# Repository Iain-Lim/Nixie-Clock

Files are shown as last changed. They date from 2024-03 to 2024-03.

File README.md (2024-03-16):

## Nixie_ver1
- The first board which house all the nixie tubes and the driver for it.

## Nixie2nd_ver1
- The second board which house the Arduino Nano, High Voltage Power Supply, Real-time clock, and other components
- Do note that there is a missing connection for the arduino to the ground.

## divergence_meter_ver_1_4
- Functional code for the clock/divergence meter.
- Yet to implement rolling numbers for the divegence number.

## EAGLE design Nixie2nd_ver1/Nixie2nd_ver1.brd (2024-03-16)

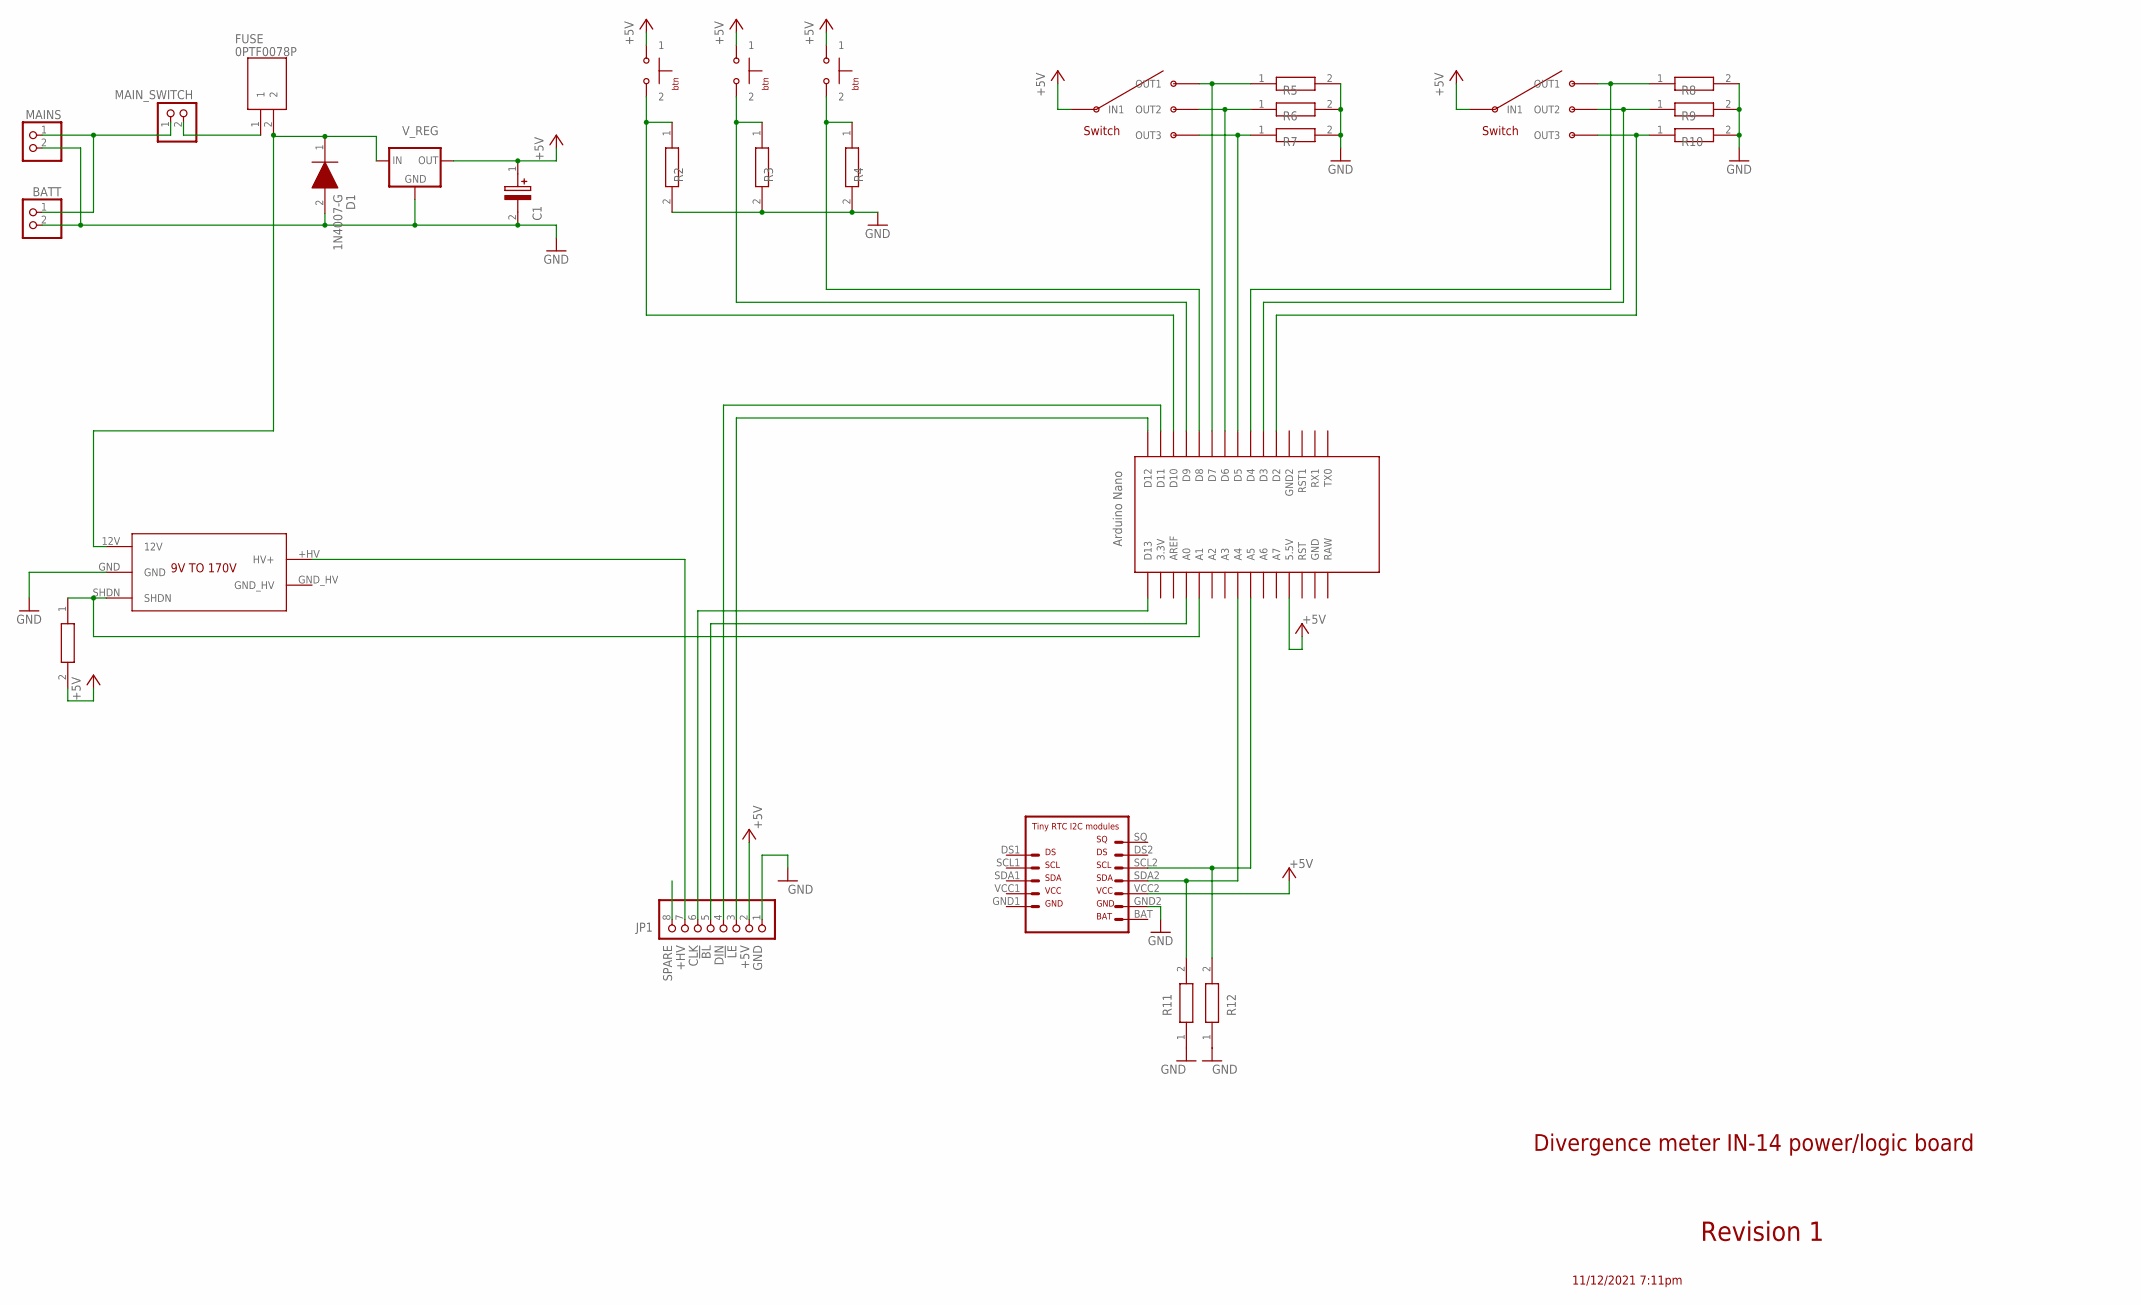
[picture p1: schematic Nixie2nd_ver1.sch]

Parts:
BATT: PINHD-1X2; 1X02
BTN_1, BTN_2, BTN_3: PUSH_BTN
C1: ESMG250ELL330ME11D; CAPPRD275W60D825H1300
D1: 1N4007-G; DIOAD1410W90L470D235
FUSE: 0PTF0078P
JP1: PINHD-1X8; 1X08
MAINS: PINHD-1X2; 1X02
MAIN_SWITCH: PINHD-1X2; 1X02
R1, R2, R3, R4, R5, R6, R7, R8, R9, R10, R11, R12: CR0805-FX-3303ELF; RESC2012X60N
SWITCH_1, SWITCH_2: 3WAY_SWITCH
U$1: NANO
U$2: VOLTAGE_9TO170VOLT_9TO170; VOLTAGE_9TO170
U$3: RTC
V_REG: 78XXS

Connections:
!BL: JP1.5, U$1.A0
!LE: JP1.3, U$1.D12
+5V: BTN_1.1, BTN_2.1, BTN_3.1, C1.1 (+), JP1.2, R1.2, SWITCH_1.IN1, SWITCH_2.IN1, U$1.5V (5.5V), U$3.VCC2, V_REG.OUT
+HV: JP1.7, U$2.+HV (HV+)
CLK: JP1.6, U$1.D13
DIN: JP1.4, U$1.D11
GND: BATT.2, C1.2 (-), D1.2 (A), JP1.1, MAINS.2, R2.2, R3.2, R4.2, R5.2, R6.2, R7.2, R8.2, R9.2, R10.2, R11.1, R12.1, U$2.GND, U$3.GND2, V_REG.GND
MAINS: BATT.1, MAINS.1, MAIN_SWITCH.1
MAINS_REG: D1.1 (K), FUSE.2, U$2.12V, V_REG.IN
unnamed: R5.1, SWITCH_1.OUT1, U$1.D7
unnamed: R6.1, SWITCH_1.OUT2, U$1.D6
unnamed: R7.1, SWITCH_1.OU3 (OUT3), U$1.D5
unnamed: R8.1, SWITCH_2.OUT1, U$1.D4
unnamed: R9.1, SWITCH_2.OUT2, U$1.D3
unnamed: R10.1, SWITCH_2.OU3 (OUT3), U$1.D2
unnamed: BTN_3.2, R4.1, U$1.D8
unnamed: BTN_2.2, R3.1, U$1.D9
unnamed: BTN_1.2, R2.1, U$1.D10
unnamed: FUSE.1, MAIN_SWITCH.2
SCL: R12.2, U$1.A5, U$3.SCL2
SDA: R11.2, U$1.A4, U$3.SDA2
SHDN: R1.1, U$1.A1, U$2.SHDN
SPARE: JP1.8

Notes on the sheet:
Divergence meter IN-14 power/logic board
11/12/2021 7:11pm
Revision 1

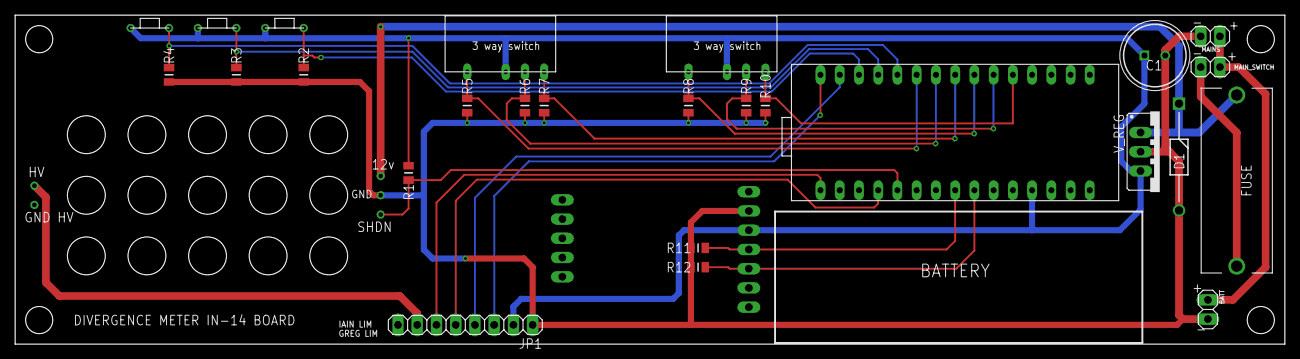
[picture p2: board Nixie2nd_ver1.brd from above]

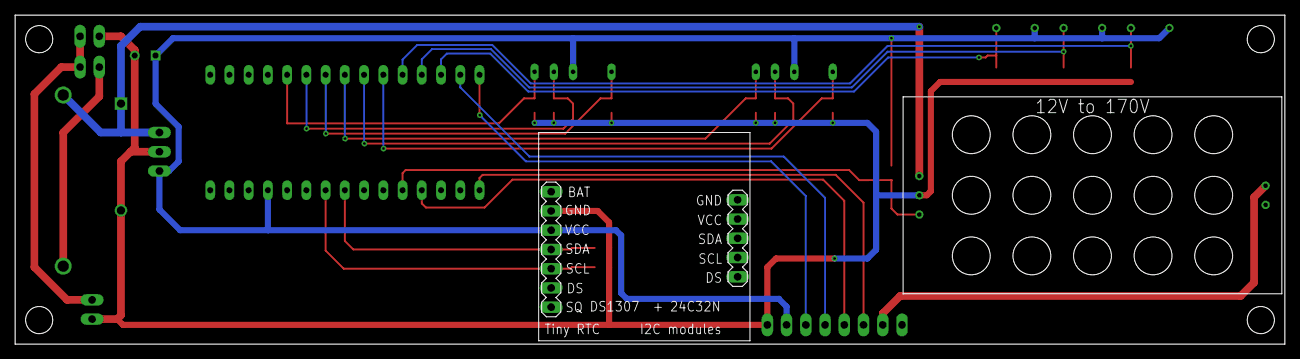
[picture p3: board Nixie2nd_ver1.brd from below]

Board: 2 copper layers, 167.6 x 43.4 mm, 28 parts (2 on the bottom side), 22 nets.

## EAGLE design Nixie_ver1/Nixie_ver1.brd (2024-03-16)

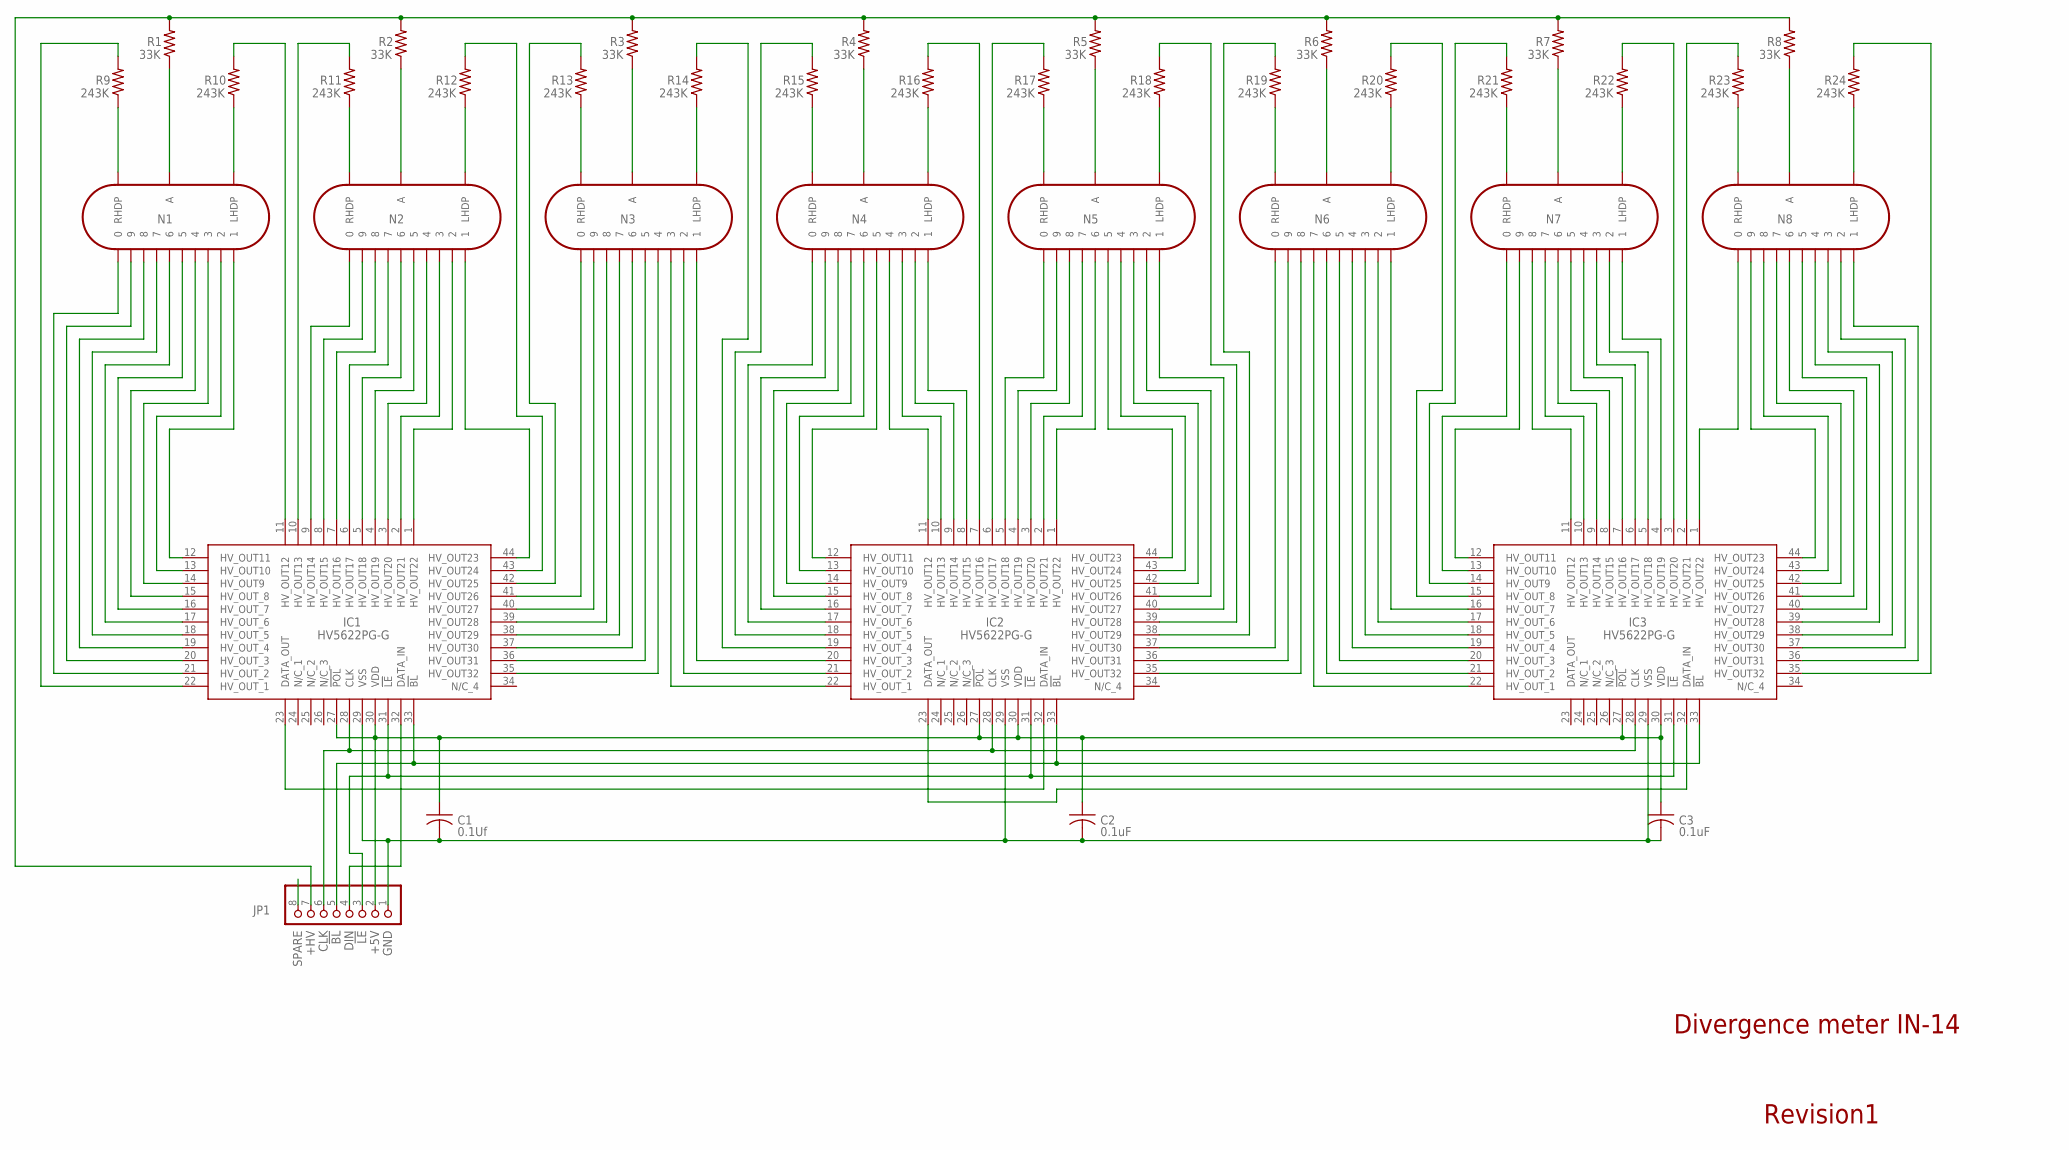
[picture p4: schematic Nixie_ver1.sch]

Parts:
C1: 0.1Uf; C025-024X044
C2, C3: 0.1uF; C025-024X044
IC1, IC2, IC3: HV5622PG-G; QFP80P1390X1390X235-44N
JP1: PINHD-1X8; 1X08
N1, N2, N3, N4, N5, N6, N7, N8: IN-14
R1, R2, R3, R4, R5, R6, R7, R8: 33K; 0204/7
R9, R10, R11, R12, R13, R14, R15, R16, R17, R18, R19, R20, R21, R22, R23, R24: 243K; 0204/7

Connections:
!BL!: IC1.33 (!BL), IC2.33 (!BL), IC3.33 (!BL), JP1.5
!LE!: IC1.31 (!LE), IC2.31 (!LE), IC3.31 (!LE), JP1.3
+5V: C1.1, C2.1, C3.1, IC1.27 (!POL), IC1.30 (VDD), IC2.27 (!POL), IC2.30 (VDD), IC3.27 (!POL), IC3.30 (VDD), JP1.2
+HV: JP1.7, R1.2, R2.2, R3.2, R4.2, R5.2, R6.2, R7.2, R8.2
CLK: IC1.28 (CLK), IC2.28 (CLK), IC3.28 (CLK), JP1.6
DIN: IC1.32 (DATA_IN), JP1.4
GND: C1.2, C2.2, C3.2, IC1.29 (VSS), IC2.29 (VSS), IC3.29 (VSS), JP1.1
unnamed: IC1.23 (DATA_OUT), IC2.32 (DATA_IN)
unnamed: IC2.23 (DATA_OUT), IC3.32 (DATA_IN)
unnamed: IC1.11 (HV_OUT12), R10.2
unnamed: IC1.13 (HV_OUT10), N1.2
unnamed: IC1.14 (HV_OUT9), N1.3
unnamed: IC1.15 (HV_OUT_8), N1.4
unnamed: IC1.16 (HV_OUT_7), N1.5
unnamed: IC1.17 (HV_OUT_6), N1.6
unnamed: IC1.18 (HV_OUT_5), N1.7
unnamed: IC1.19 (HV_OUT_4), N1.8
unnamed: IC1.20 (HV_OUT_3), N1.9
unnamed: IC1.12 (HV_OUT11), N1.1
unnamed: IC1.21 (HV_OUT_2), N1.0
unnamed: IC1.22 (HV_OUT_1), R9.2
unnamed: N1.RHDP, R9.1
unnamed: N1.LHDP, R10.1
unnamed: IC1.10 (HV_OUT13), R11.2
unnamed: N1.A, R1.1
unnamed: N2.RHDP, R11.1
unnamed: N2.A, R2.1
unnamed: N2.LHDP, R12.1
unnamed: IC1.9 (HV_OUT14), N2.0
unnamed: IC1.8 (HV_OUT15), N2.9
unnamed: IC1.7 (HV_OUT16), N2.8
unnamed: IC1.6 (HV_OUT17), N2.7
unnamed: IC1.5 (HV_OUT18), N2.6
unnamed: IC1.4 (HV_OUT19), N2.5
unnamed: IC1.3 (HV_OUT20), N2.4
unnamed: IC1.2 (HV_OUT21), N2.3
unnamed: IC1.1 (HV_OUT22), N2.2
unnamed: IC1.44 (HV_OUT23), N2.1
unnamed: IC1.43 (HV_OUT24), R12.2
unnamed: IC1.42 (HV_OUT25), R13.2
unnamed: N3.RHDP, R13.1
unnamed: N3.A, R3.1
unnamed: N3.LHDP, R14.1
unnamed: IC1.41 (HV_OUT26), N3.0
unnamed: IC1.40 (HV_OUT27), N3.9
unnamed: IC1.39 (HV_OUT28), N3.8
unnamed: IC1.38 (HV_OUT29), N3.7
unnamed: IC1.37 (HV_OUT30), N3.6
unnamed: IC1.36 (HV_OUT31), N3.5
unnamed: IC1.35 (HV_OUT32), N3.4
unnamed: IC2.22 (HV_OUT_1), N3.3
unnamed: IC2.21 (HV_OUT_2), N3.2
unnamed: IC2.20 (HV_OUT_3), N3.1
unnamed: IC2.19 (HV_OUT_4), R14.2
unnamed: IC2.18 (HV_OUT_5), R15.2
unnamed: N4.RHDP, R15.1
unnamed: N4.A, R4.1
unnamed: N4.LHDP, R16.1
unnamed: IC2.17 (HV_OUT_6), N4.0
unnamed: IC2.16 (HV_OUT_7), N4.9
unnamed: IC2.15 (HV_OUT_8), N4.8
unnamed: IC2.14 (HV_OUT9), N4.7
unnamed: IC2.13 (HV_OUT10), N4.6
unnamed: IC2.1 (HV_OUT22), N5.6
unnamed: IC2.11 (HV_OUT12), N4.4
unnamed: IC2.10 (HV_OUT13), N4.3
unnamed: IC2.9 (HV_OUT14), N4.2
unnamed: IC2.8 (HV_OUT15), N4.1
unnamed: IC2.7 (HV_OUT16), R16.2
unnamed: IC2.6 (HV_OUT17), R17.2
unnamed: N5.RHDP, R17.1
unnamed: N5.A, R5.1
unnamed: N5.LHDP, R18.1
unnamed: IC2.5 (HV_OUT18), N5.0
unnamed: IC2.4 (HV_OUT19), N5.9
unnamed: IC2.3 (HV_OUT20), N5.8
unnamed: IC2.2 (HV_OUT21), N5.7
unnamed: N6.RHDP, R19.1
unnamed: IC2.44 (HV_OUT23), N5.5
unnamed: IC2.43 (HV_OUT24), N5.4
unnamed: IC2.42 (HV_OUT25), N5.3
unnamed: IC2.41 (HV_OUT26), N5.2
unnamed: IC2.40 (HV_OUT27), N5.1
unnamed: IC2.39 (HV_OUT28), R18.2
unnamed: IC2.38 (HV_OUT29), R19.2
unnamed: IC2.12 (HV_OUT11), N4.5
unnamed: N6.A, R6.1
unnamed: N6.LHDP, R20.1
unnamed: N7.RHDP, R21.1
unnamed: N7.A, R7.1
unnamed: N7.LHDP, R22.1
unnamed: N8.RHDP, R23.1
unnamed: N8.A, R8.1
unnamed: N8.LHDP, R24.1
unnamed: IC2.37 (HV_OUT30), N6.0
unnamed: IC2.36 (HV_OUT31), N6.9
unnamed: IC2.35 (HV_OUT32), N6.8
unnamed: IC3.22 (HV_OUT_1), N6.7
unnamed: IC3.21 (HV_OUT_2), N6.6
unnamed: IC3.20 (HV_OUT_3), N6.5
unnamed: IC3.19 (HV_OUT_4), N6.4
unnamed: IC3.18 (HV_OUT_5), N6.3
unnamed: IC3.17 (HV_OUT_6), N6.2
unnamed: IC3.16 (HV_OUT_7), N6.1
unnamed: IC3.15 (HV_OUT_8), R20.2
unnamed: IC3.14 (HV_OUT9), R21.2
unnamed: IC3.13 (HV_OUT10), N7.0
unnamed: IC3.12 (HV_OUT11), N7.9
unnamed: IC3.11 (HV_OUT12), N7.8
unnamed: IC3.10 (HV_OUT13), N7.7
unnamed: IC3.9 (HV_OUT14), N7.6
unnamed: IC3.8 (HV_OUT15), N7.5
unnamed: IC3.7 (HV_OUT16), N7.4
unnamed: IC3.6 (HV_OUT17), N7.3
unnamed: IC3.5 (HV_OUT18), N7.2
unnamed: IC3.4 (HV_OUT19), N7.1
unnamed: IC3.3 (HV_OUT20), R22.2
unnamed: IC3.2 (HV_OUT21), R23.2
unnamed: IC3.1 (HV_OUT22), N8.0
unnamed: IC3.44 (HV_OUT23), N8.9
unnamed: IC3.43 (HV_OUT24), N8.8
unnamed: IC3.42 (HV_OUT25), N8.7
unnamed: IC3.41 (HV_OUT26), N8.6
unnamed: IC3.40 (HV_OUT27), N8.5
unnamed: IC3.39 (HV_OUT28), N8.4
unnamed: IC3.38 (HV_OUT29), N8.3
unnamed: IC3.37 (HV_OUT30), N8.2
unnamed: IC3.36 (HV_OUT31), N8.1
unnamed: IC3.35 (HV_OUT32), R24.2
SPARE: JP1.8

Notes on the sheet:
Divergence meter IN-14
Revision1

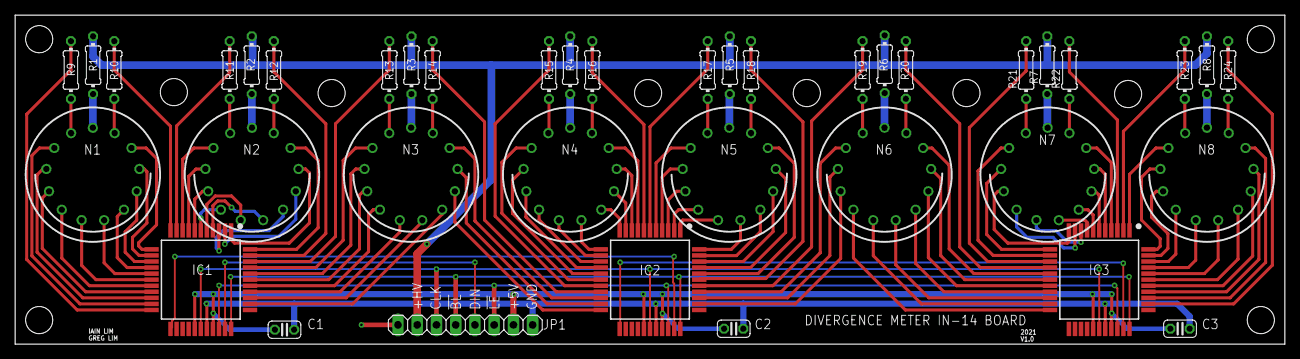
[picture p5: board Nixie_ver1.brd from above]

Board: 2 copper layers, 167.6 x 43.4 mm, 39 parts (0 on the bottom side), 129 nets.

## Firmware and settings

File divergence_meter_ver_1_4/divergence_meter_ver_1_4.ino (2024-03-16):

#include <Wire.h>
#include <TimeLib.h>
#include <DS1307RTC.h>

int latchPin = 12;
int clockPin = 13;
int dataPin = 11;
int blankPin = 14;

int SHDNPin = 15;

//Mode
int SW1_R = 2; //Divergence
int SW1_M = 3; //Date
int SW1_L = 4; //Time

//Settings
int SW2_R = 5; //Special
int SW2_M = 6; //Setting
int SW2_L = 7; //Normal

//buttons
int BTN_L = 8; //Next
int BTN_M = 9; //Up
int BTN_R = 10;//Down

/*
  SCLPin = 19
  SDAPin = 18
*/


bool tubeDigitData[8][12] = {0};
//first value is the tube, 0 is MSB;
//second value is the value, 0 is 0, 10 is Ldot, 11 is Rdot
//bool 1 is light up

bool FinalStringData[96] = {0};
//Final data to be shifted out

bool PrevFinalStringData[96] = {0};
//Previous final data to be shifted out

int SettingBlinkTimeConst = 500; //time const for ON or OFF state when blinking in milliseconds
unsigned long SettingBlinkTime = 0; //time pass for ON or OFF state when blinking
//bool SettingBlink = 0; //ON or OFF state when blinking
int SettingPair = 1; //The pair of digits being set with 1(hr/date), 2(min/month), 3(sec/year)
//Setting mode for Time and Date
int prev_sec = 60;
//to determine if the time has changed

int PrevStateSW1 = 1; //1:date 2:time 3:divergence
int PrevStateSW2 = 1; //1:Normal 3:setting 3:special
bool PrevStateBTN_L = 0; //Next
bool PrevStateBTN_M = 0; //Up
bool PrevStateBTN_R = 0; //Down
//previous state of the inputs

bool LowHighBTN_L = 0; //Next
bool LowHighBTN_M = 0; //Up
bool LowHighBTN_R = 0; //Down
//current state of the inputs

unsigned long debounceTimeBTN_L = 0;
unsigned long debounceTimeBTN_M = 0;
unsigned long debounceTimeBTN_R = 0;
int debounceTime = 50;
//debouncing
int numbertest=0;

//Divergence number
long DivergenceNum[12] = {10130426, 571024, 571015, 523299, 456903, 409420, 337187, 409431, 456914, 523307, 571046, 10130205};
long SteinsGateNum = 10048596;
int CurrentDiv = 0;

void setup() {
  //Serial.println(mainData, BIN);
  pinMode(latchPin, OUTPUT);
  pinMode(dataPin, OUTPUT);
  pinMode(clockPin, OUTPUT);
  pinMode(blankPin, OUTPUT);

  pinMode(SHDNPin, OUTPUT);

  pinMode(SW1_R, INPUT);
  pinMode(SW1_M, INPUT);
  pinMode(SW1_L, INPUT);
  pinMode(SW2_R, INPUT);
  pinMode(SW2_M, INPUT);
  pinMode(SW2_L, INPUT);
  pinMode(BTN_L, INPUT);
  pinMode(BTN_M, INPUT);
  pinMode(BTN_R, INPUT);

  digitalWrite(blankPin, LOW);
  digitalWrite(SHDNPin, HIGH);

  Serial.begin(9600);
  while (! Serial); // Wait untilSerial is ready
  Serial.println("Test");

  tdd_reset();
  tdd_updateShiftRegister();
  digitalWrite(blankPin, HIGH);
  digitalWrite(SHDNPin, LOW);


}

void loop() {
  bool CurrentstateBTN_L = digitalRead(BTN_L);
  bool CurrentstateBTN_M = digitalRead(BTN_M);
  bool CurrentstateBTN_R = digitalRead(BTN_R);

  if ((PrevStateBTN_L != CurrentstateBTN_L) && (millis() - debounceTimeBTN_L > debounceTime)) {
    LowHighBTN_L = 1;
    numbertest++;
  }
  else {
    LowHighBTN_L = 0;
  }
  if(CurrentstateBTN_L){
    debounceTimeBTN_L = millis();
  }

  if ((PrevStateBTN_M != CurrentstateBTN_M) && (millis() - debounceTimeBTN_M > debounceTime)) {
    LowHighBTN_M = 1;
    numbertest++;
  }
  else {
    LowHighBTN_M = 0;
  }
  if(CurrentstateBTN_M){
    debounceTimeBTN_M = millis();
  }

  if ((PrevStateBTN_R != CurrentstateBTN_R) && (millis() - debounceTimeBTN_R > debounceTime)) {
    LowHighBTN_R = 1;
    numbertest++;
  }
  else {
    LowHighBTN_R = 0;
  }
  if(CurrentstateBTN_R){
    debounceTimeBTN_R = millis();
  }

  PrevStateBTN_L = CurrentstateBTN_L;
  PrevStateBTN_M = CurrentstateBTN_M;
  PrevStateBTN_R = CurrentstateBTN_R;


  if (digitalRead(SW1_L)) {
    printDATE();
    Serial.print("Date ");
  }
  else if (digitalRead(SW1_M)) {
    printTIME();
    Serial.print("Time ");
  }
  else if (digitalRead(SW1_R)) {
    printDIVERGENCE();
    Serial.print("DIVERGENCE ");
  }
  else {
    tdd_reset();
    tubeDigitData[7][1] = 1;
  }

  tdd_updateShiftRegister();
  tdd_reset();
  Serial.println();
  Serial.print(numbertest); //test
  Serial.print("  ");       //test
  Serial.print("BTN_L:");
  Serial.print(LowHighBTN_L);
  Serial.print(" BTN_M:");
  Serial.print(LowHighBTN_M);
  Serial.print(" BTN_R:");
  Serial.print(LowHighBTN_R);
  Serial.println();
  Serial.println();

  /*print0To9DotDotRolling();
    tdd_reset();
    tdd_updateShiftRegister();
    delay(1000);*/

}


//----------------------------------
//------------FUNCTIONS-------------
//----------------------------------


//prints the current 24hr time in HH MM SS
void printTIME()
{
  tmElements_t tm;
  if (RTC.read(tm)) {
    tubeDigitData[0][tm.Hour / 10] = 1;
    tubeDigitData[1][tm.Hour % 10] = 1;

    tubeDigitData[3][tm.Minute / 10] = 1;
    tubeDigitData[4][tm.Minute % 10] = 1;

    tubeDigitData[6][tm.Second / 10] = 1;
    tubeDigitData[7][tm.Second % 10] = 1;

    if (tm.Second % 2) {
      tubeDigitData[2][10] = 1;
      tubeDigitData[5][10] = 1;
    }
    else {
      tubeDigitData[2][11] = 1;
      tubeDigitData[5][11] = 1;
    }

  } else {
    if (RTC.chipPresent()) {
      Serial.println("The DS1307 is stopped.  Please run the SetTime");
      Serial.println("example to initialize the time and begin running.");
      Serial.println();
    } else {
      Serial.println("DS1307 read error!  Please check the circuitry.");
      Serial.println();
    }
  }

  if (digitalRead(SW2_M)) {
    if (PrevStateSW1 != 2) {
      SettingBlinkTime = 1;
      PrevStateSW1 = 2;
      SettingPair = 1;
    }

    if (prev_sec != tm.Second) {
      SettingBlinkTime = millis();
    }

    if (((millis() - SettingBlinkTime) / SettingBlinkTimeConst) % 2 == 0) {
      if (SettingPair == 1) {
        tubeDigitData[0][tm.Hour / 10] = 0;
        tubeDigitData[1][tm.Hour % 10] = 0;
      }
      else if (SettingPair == 2) {
        tubeDigitData[3][tm.Minute / 10] = 0;
        tubeDigitData[4][tm.Minute % 10] = 0;
      }
      else {
        tubeDigitData[6][tm.Second / 10] = 0;
        tubeDigitData[7][tm.Second % 10] = 0;
      }
    }
  }
  prev_sec = tm.Second;
}


//prints the current Date DDMMYYYY
void printDATE()
{
  tmElements_t tm;

  if (RTC.read(tm)) {
    tubeDigitData[0][tm.Day / 10] = 1;
    tubeDigitData[1][tm.Day % 10] = 1;

    tubeDigitData[3][tm.Month / 10] = 1;
    tubeDigitData[4][tm.Month % 10] = 1;

    //tubeDigitData[4][tmYearToCalendar(tm.Year)/1000] = 1;
    //tubeDigitData[5][tmYearToCalendar(tm.Year)/100%10] = 1;
    tubeDigitData[6][tmYearToCalendar(tm.Year) / 10 % 10] = 1;
    tubeDigitData[7][tmYearToCalendar(tm.Year) % 10] = 1;

    tubeDigitData[2][10] = 1;
    tubeDigitData[5][10] = 1;


  } else {
    if (RTC.chipPresent()) {
      Serial.println("The DS1307 is stopped.  Please run the SetTime");
      Serial.println("example to initialize the time and begin running.");
      Serial.println();
    } else {
      Serial.println("DS1307 read error!  Please check the circuitry.");
      Serial.println();
    }
  }

  if (digitalRead(SW2_M)) {
    if (PrevStateSW1 != 1) {
      SettingBlinkTime = 1;
      PrevStateSW1 = 1;
      SettingPair = 1;
    }

    if (prev_sec != tm.Second) {
      SettingBlinkTime = millis();
    }

    if (((millis() - SettingBlinkTime) / SettingBlinkTimeConst) % 2 == 0) {
      if (SettingPair == 1) {
        tubeDigitData[0][tm.Day / 10] = 0;
        tubeDigitData[1][tm.Day % 10] = 0;
      }
      else if (SettingPair == 2) {
        tubeDigitData[3][tm.Month / 10] = 0;
        tubeDigitData[4][tm.Month % 10] = 0;
      }
      else {
        tubeDigitData[6][tm.Year / 10] = 0;
        tubeDigitData[7][tm.Year % 10] = 0;
      }
    }
  }
  prev_sec = tm.Second;
}


void printDIVERGENCE()
{
  long tempDivergenceNum = DivergenceNum[CurrentDiv];

  for (int i = 7; i >= 0; i--) {
    if (i == 1) {
      tubeDigitData[i][11] = 1;
    }
    else {
      tubeDigitData[i][tempDivergenceNum % 10] = 1;
    }
    tempDivergenceNum = tempDivergenceNum / 10;
  }


}


//----------------------------------
//----------BASE FUNCTION-----------
//----------------------------------


//This function is good
//uses tube digit data to update
void tdd_updateShiftRegister() {

  bool Temp0DataSwap; //swapping of 0 digit and Rdot

  for (int i = 0; i < 8; i++) {
    Temp0DataSwap = tubeDigitData[i][0];
    tubeDigitData[i][0] = tubeDigitData[i][10];
    tubeDigitData[i][10] = Temp0DataSwap;
  }

  for (int i = 0; i < 8; i++) {
    for (int j = 0; j < 12; j++) {
      int count = 12 * i + j;
      // Serial.println(count);
      FinalStringData[count] = tubeDigitData[i][j];
    }
  }
  //Serial.println("Binary");
  for (int i = 0; i < 96; i++) {
    //Serial.print(FinalStringData[i]);
  }
  //Serial.println("");

  if (FinalStringData != PrevFinalStringData) {
    digitalWrite(latchPin, LOW);
    for (int i = 0; i < 12; i++) {
      byte temp8Bits = 0; //8 bits
      for (int j = 0; j < 8; j++) {
        bitWrite(temp8Bits, 7 - j, FinalStringData[i * 8 + j]);
      }
      shiftOut(dataPin, clockPin, MSBFIRST, temp8Bits);
      //Serial.print(temp8Bits, BIN);
      //Serial.print(" ");
    }
    digitalWrite(latchPin, HIGH);
    //Serial.println("");
  }
  memcpy(PrevFinalStringData, FinalStringData, 96);
}


//resets data to all 0
void tdd_reset() {
  for (int i = 0; i < 8; i++) {
    for (int j = 0; j < 12; j++) {
      tubeDigitData[i][j] = 0;
    }
  }
}



//----------------------------------
//----------TEST FUNCTION-----------
//----------------------------------


// prints 0,1,...,9, Ldot, Rdot
// all tubes print the same
void print0To9DotDotRolling() {
  for (int i = 0; i < 12; i++) {
    for (int j = 0; j < 8; j++) {
      tubeDigitData[j][i] = 1;
    }
    tdd_updateShiftRegister();

    delay(1000);
    tdd_reset();
  }
}
